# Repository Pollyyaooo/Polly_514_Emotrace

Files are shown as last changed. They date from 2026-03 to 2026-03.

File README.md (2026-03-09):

# EmoTrace
#### MSTI TECHIN 514 Final Project           
#### 01/06/2026-03/06/2026
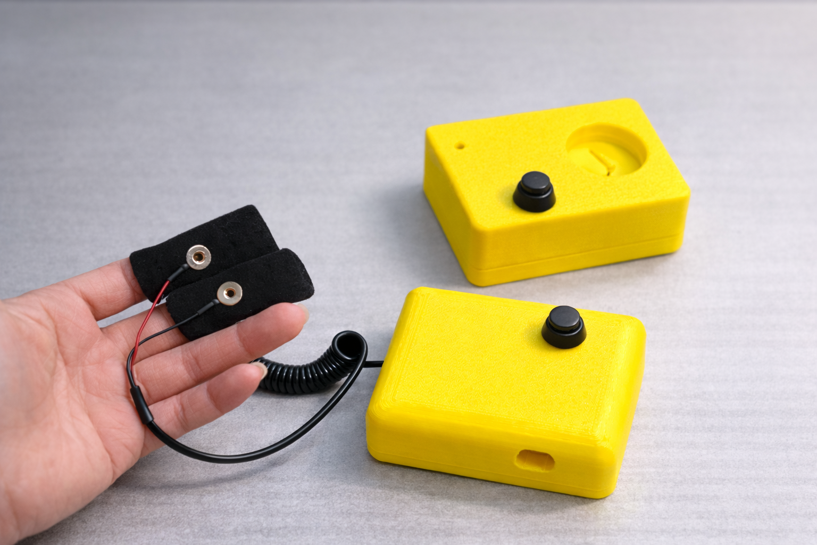
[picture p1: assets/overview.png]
overview


# OVERVIEW
## One Sentence Explanation
EmoTrace uses GSR to sense physiological arousal and express a person’s current emotional state in real time.

## Problem being Solved
Emotion is a continuously changing internal state, but it is difficult to observe directly. Most of the time, we only understand our emotions afterward, through memory or language, rather than seeing how they change in the moment.

If emotional states could be __externalized__, they might become something that both the individual and others can notice in real time.

## The Proposed Solution
EmoTrace measures physiological arousal through galvanic skin response (GSR) and expresses these changes using a stepper-motor-driven physical needle.

The system consists of two physically separated devices connected wirelessly via BLE: a sensing device, which captures and processes physiological signals, and a display device, which translates these signals into slow mechanical movement.

This separation allows the relationship between the person being sensed and the person observing the display to remain flexible. They can be the same person or different people. In this way, emotional states are externalized as a physical trace that can be noticed and reflected upon.

## Working Video

[Watch the demo video](https://drive.google.com/file/d/1t5GnzGR31K_5sYIAPt7pJoVDXnYhjY41/view?usp=sharing)

## System Architecture

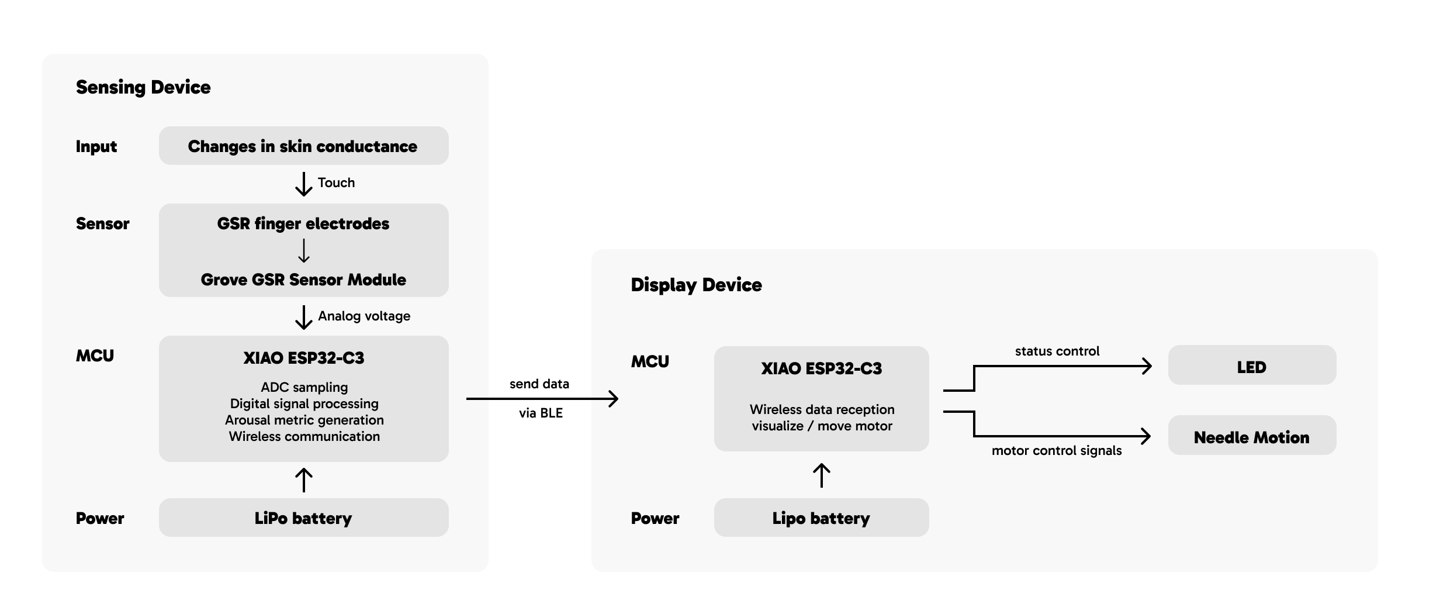
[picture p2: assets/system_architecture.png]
System Architecture


# SENSING DEVICE
## BOM
- 1 * [XIAO ESP32S3](https://www.digikey.com/en/products/detail/seeed-technology-co-ltd/113991054/16652880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)
- 1 * [1000mAh Lipo battery](https://www.digikey.com/en/products/detail/adafruit-industries-llc/258/5054544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)
- 1 * [Grove GSR Sensor](https://www.digikey.com/en/products/detail/seeed-technology-co-ltd/101020052/5488086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)
- 1 * [SPST Round Push Button Switch](https://www.walmart.com/ip/SPST-MOMENTARY-ON-PUSH-BUTTON-SWITCH-ROUND/166980349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)
- SMD resistors and capacitors
- Several JST connectors
- 3D printing enclosure

## Schematic Diagram
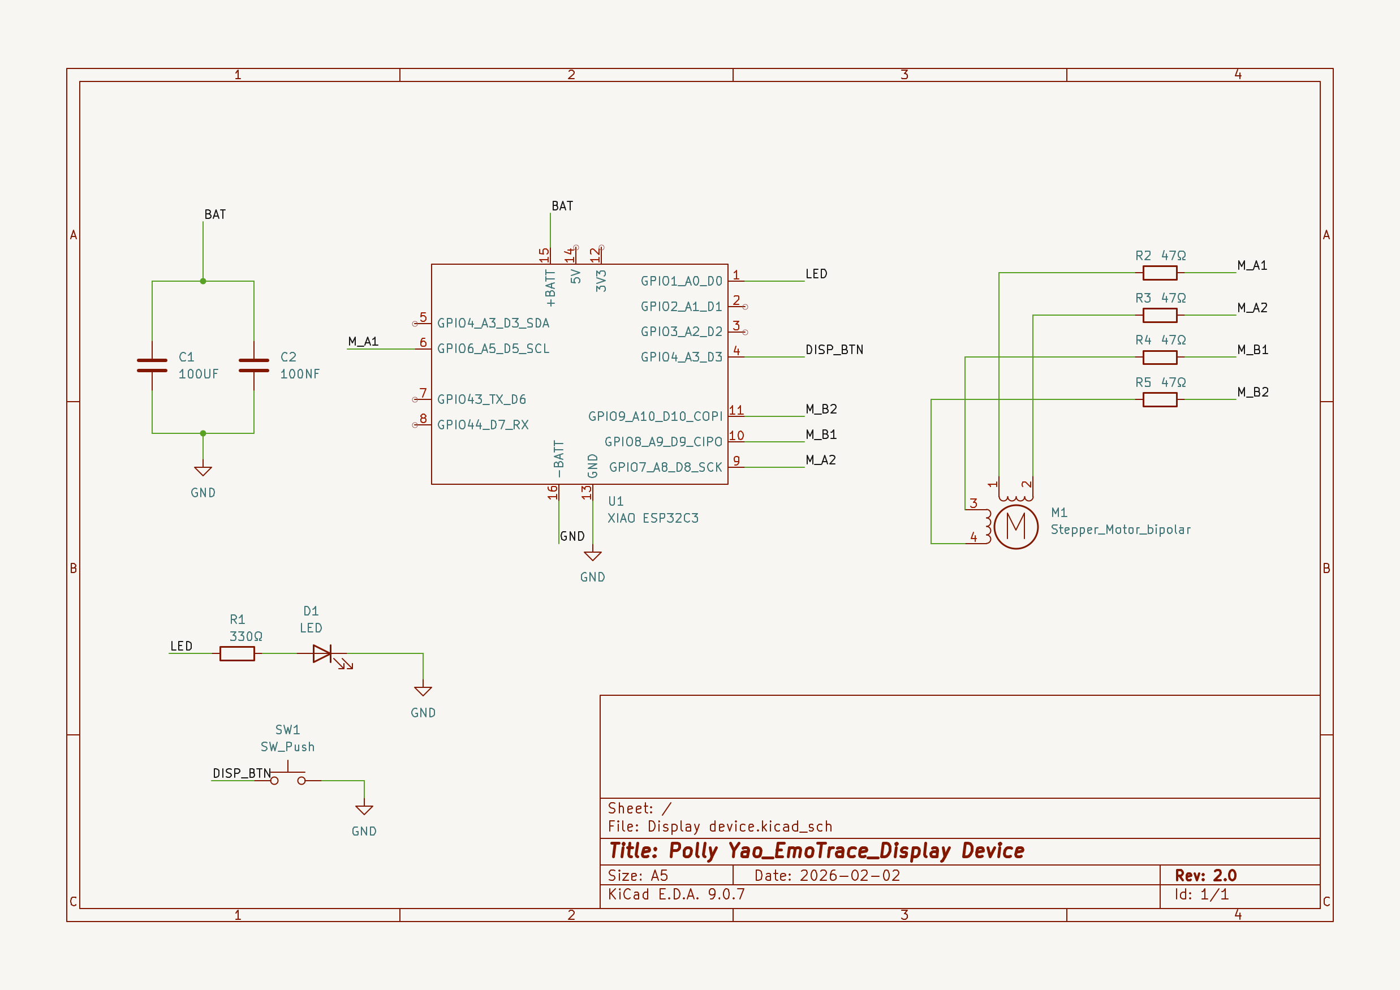
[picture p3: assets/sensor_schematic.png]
sensor_schematic


## Gallery
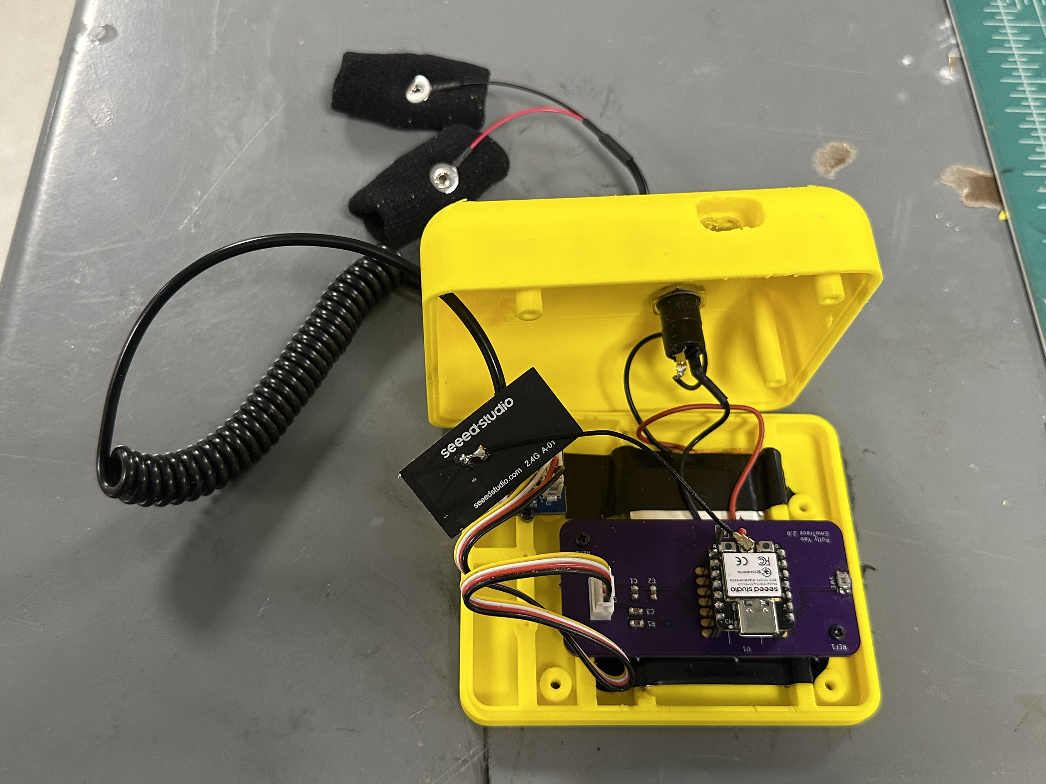
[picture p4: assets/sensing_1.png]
sensing_1

sensing_2

# DISPLAY DEVICE
## BOM
- 1 * [XIAO ESP32S3](https://www.digikey.com/en/products/detail/seeed-technology-co-ltd/113991054/16652880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)
- 1 * [820mAh Lipo battery](https://www.digikey.com/en/products/detail/adafruit-industries-llc/258/5054544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)
- 1 * [Stepper motor gauge](https://www.adafruit.com/product/2424)
- 1 * [SPST Round Push Button Switch](https://www.walmart.com/ip/SPST-MOMENTARY-ON-PUSH-BUTTON-SWITCH-ROUND/166980349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)
- SMD leds,resistors and capacitors
- 3D printing enclosure

## Schematic Diagram
display_schematic

## Gallery
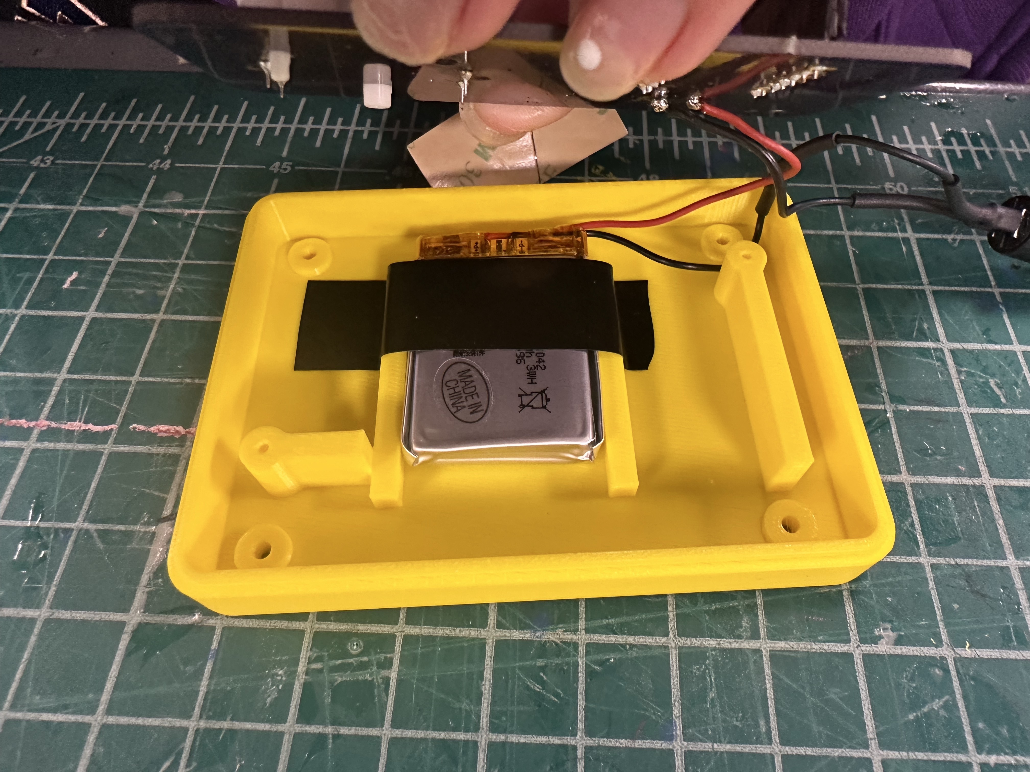
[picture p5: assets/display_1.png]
display_1

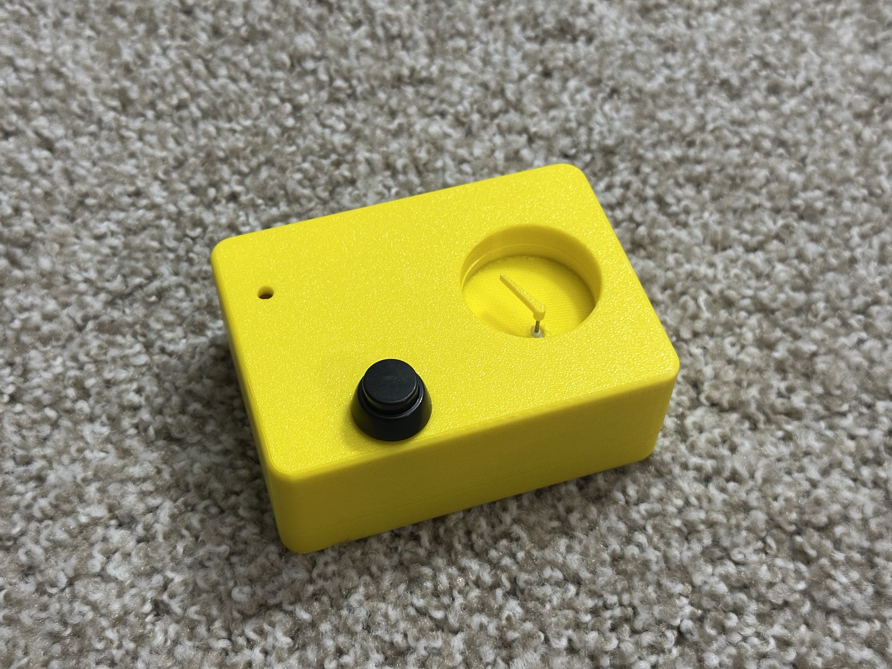
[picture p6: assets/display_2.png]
display_2


# BATTERY CONSIDERATIONS
Each device is powered by a LiPo battery with __a physical switch__ that can completely cut power to the ESP32, while __the onboard charging circuit__ allows the ESP32 to recharge the battery via USB; additionally, both devices implement __multiple operating states__ (off, monitoring/active for sensing and off, scanning/displaying for display) with light-sleep behavior to minimize continuous power consumption.

## Sensing Device
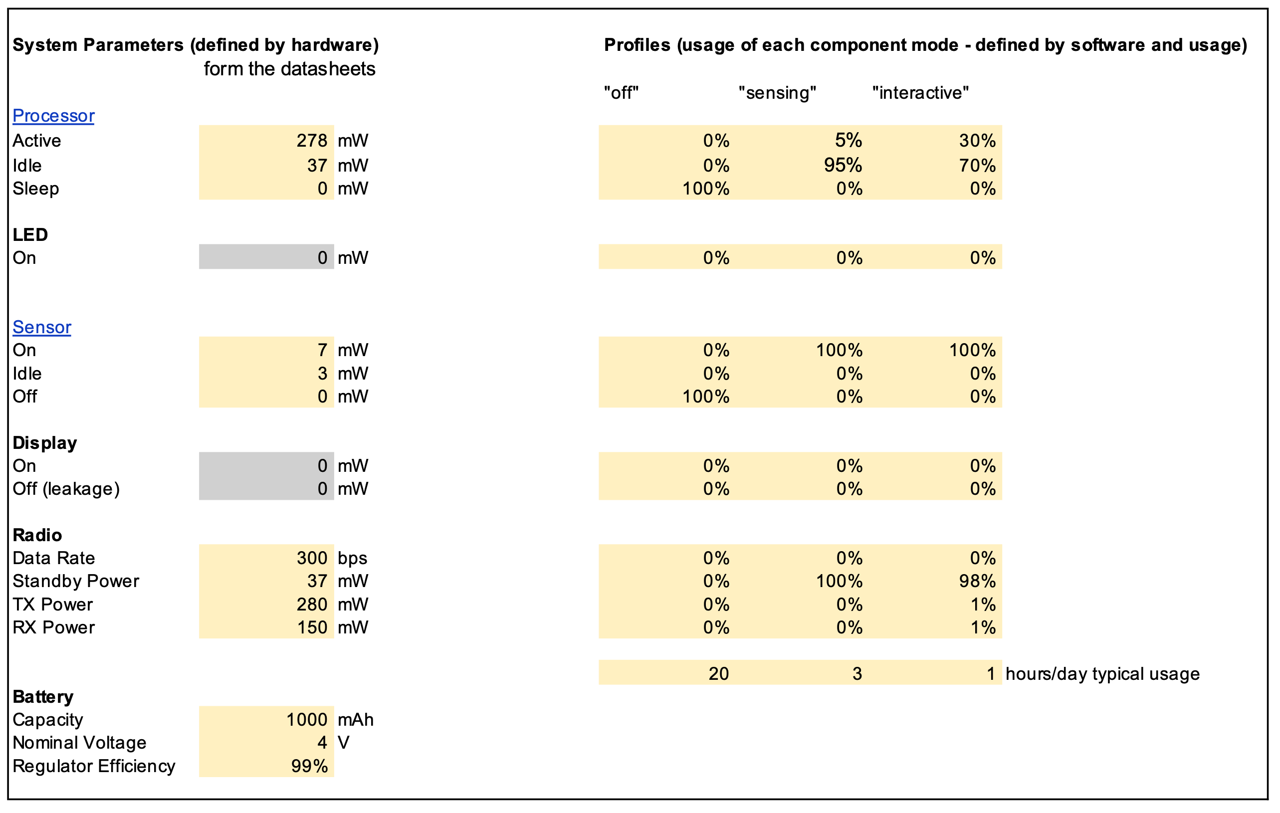
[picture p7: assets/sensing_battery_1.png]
batterysensing_1

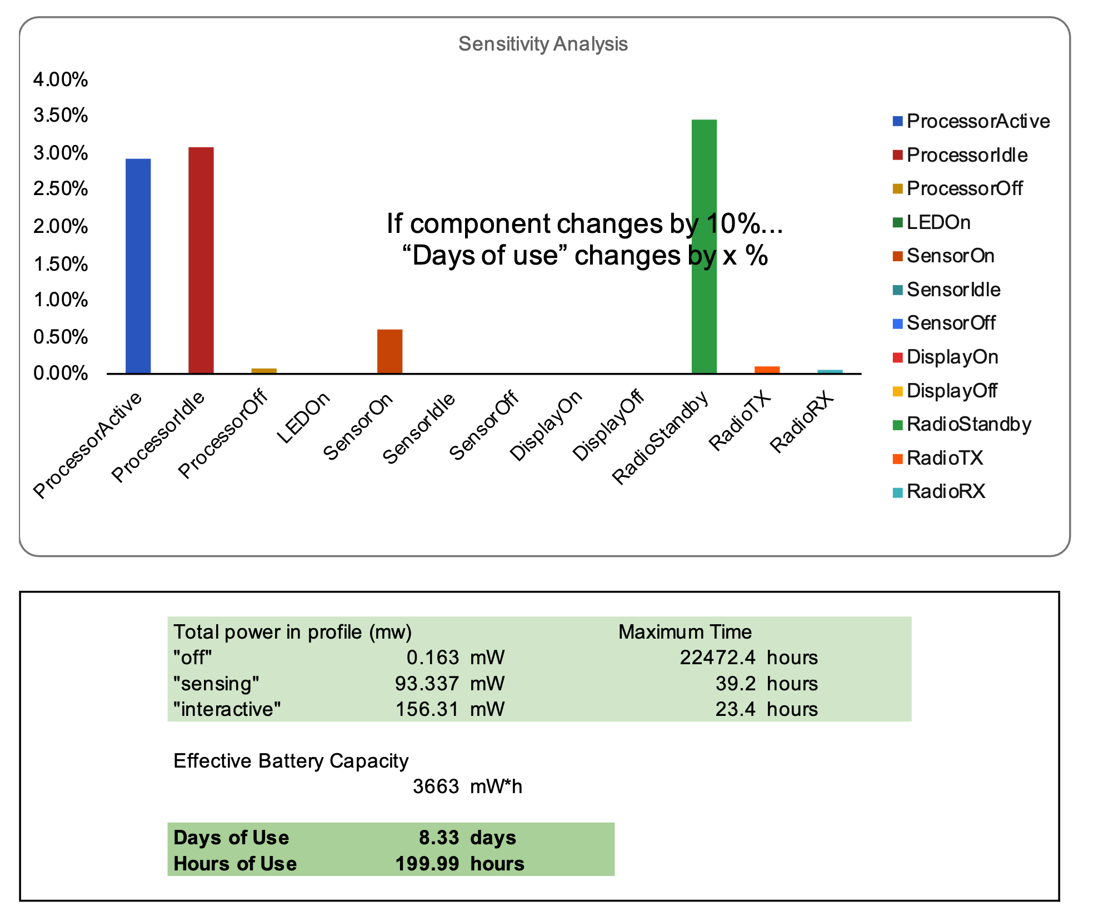
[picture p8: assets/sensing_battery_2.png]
batterysensing_2


Spreadsheet link:  
https://1drv.ms/x/c/3520740a59bca320/IQDMDjtJkVfMQYsOUzpoie-YAZGBVunHImL63yKkG8l4-dY?e=yHCJq8

## Display Device
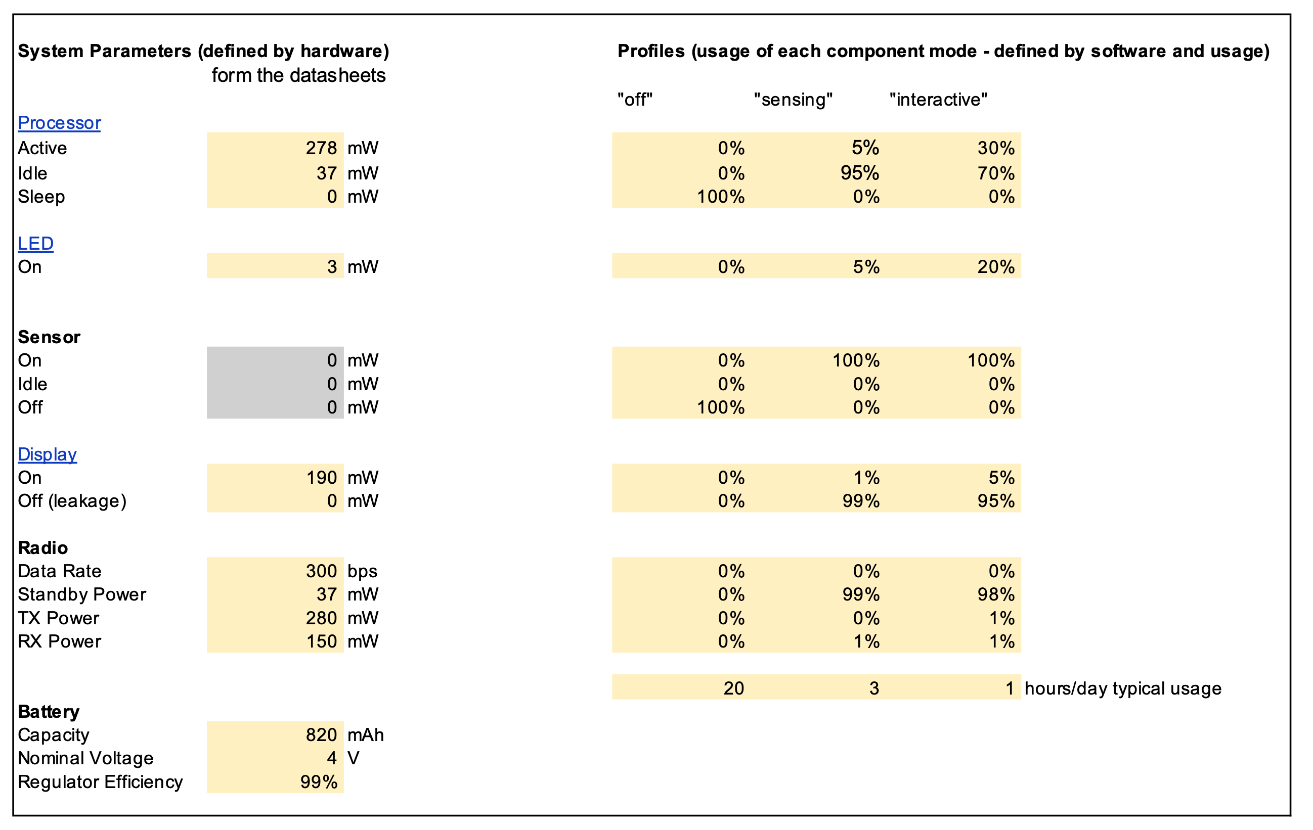
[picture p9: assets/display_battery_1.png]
batterydisplay_1

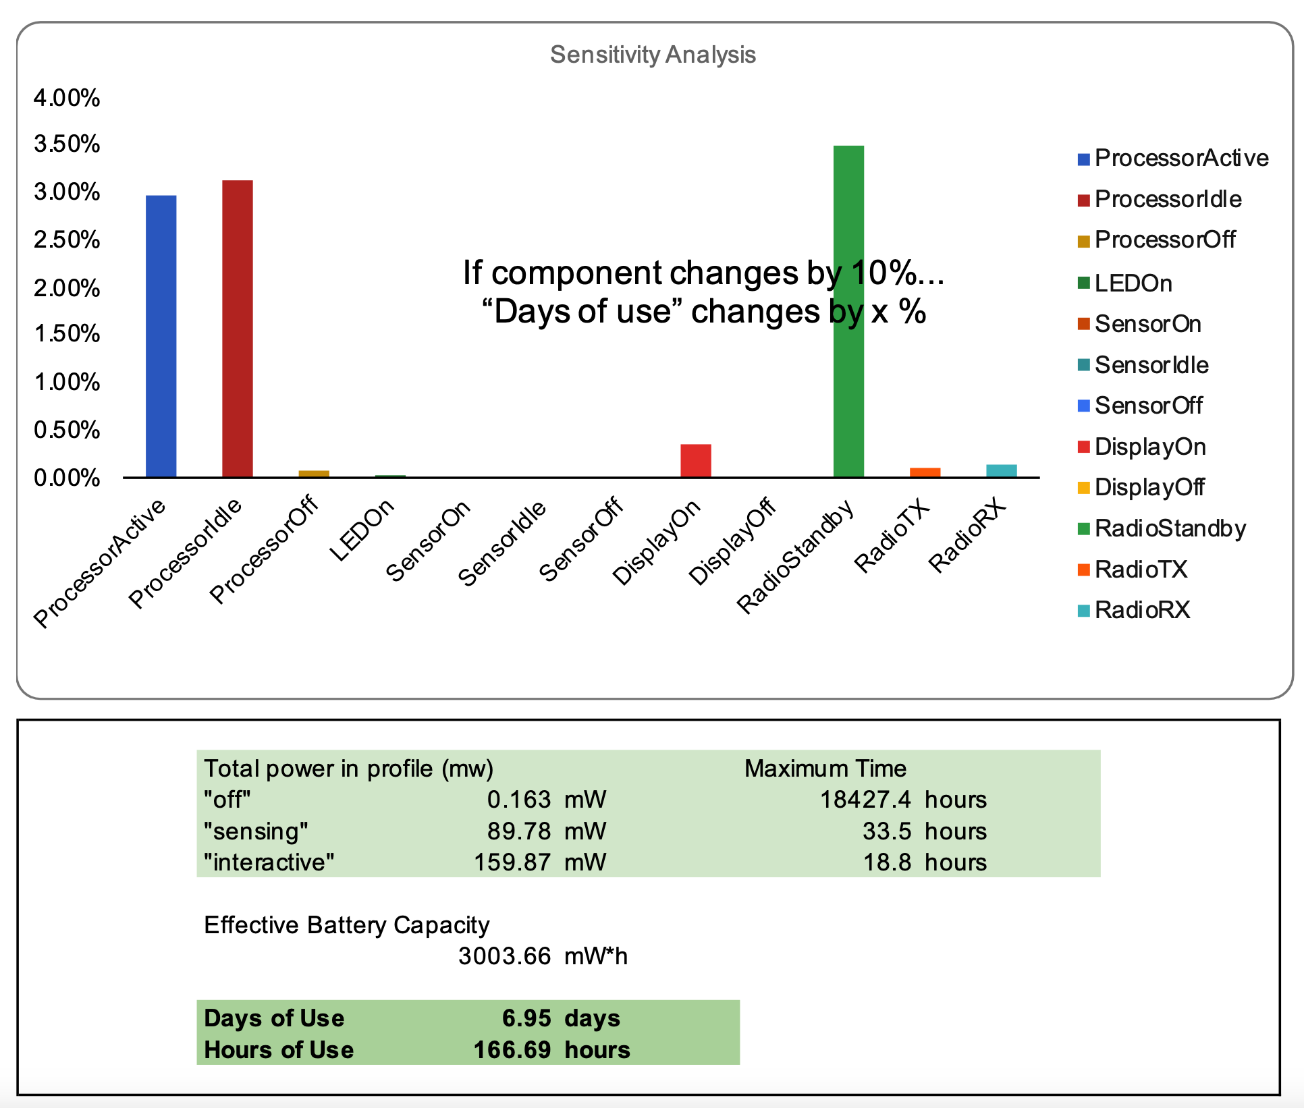
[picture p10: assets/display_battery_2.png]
batterydisplay_2


Spreadsheet link:  
https://1drv.ms/x/c/3520740a59bca320/IQBtffllcoQcSJlxG03brPWNAZ11j2MDRlCTxOjXR5vgqAk?e=tpQcXu

# BUDGET SUMMARY
| Component | Price |
|---|---|
| Grove GSR Module | $32.99 / $36.69 |
| CQRobot JST PH 2.0 mm Pitch Connector Kit | $6.99 / $7.71 |
| EVQ-P7A01P | $0.56 |
| ESP32C3 | $4.99 |
| **Total** | **$49.95** |

# FUTURE WORK
- Improved enclosure and interaction design
Develop a more refined enclosure with better integration of the charging port, button, and LED indicators, moving beyond the current PCB housing toward a more intentional human–device interaction.

- Multi-sensor emotional sensing
Incorporate additional physiological sensors to capture emotional states from multiple signals rather than relying solely on GSR.

- More robust signal processing
Improve data processing and filtering methods so that emotional changes are translated into clearer and more stable physical motion.

- Cost optimization
Explore alternative sourcing platforms to reduce the overall hardware cost of the system.

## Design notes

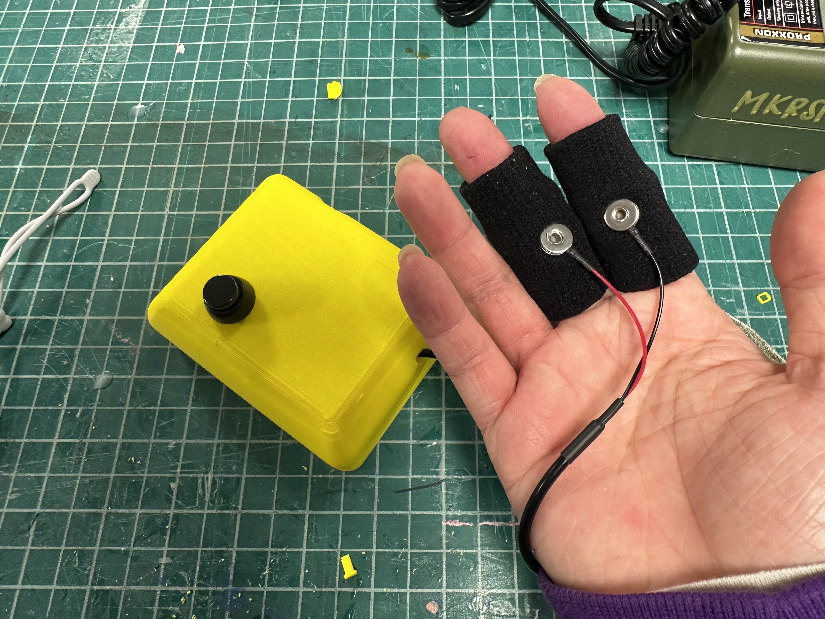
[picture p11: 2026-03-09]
assets/detailed_devices.png

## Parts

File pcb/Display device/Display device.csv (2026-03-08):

Source: | /Users/yaoyitong/Documents/Pollyyaooo-Polly_514_Final/schematics/Display device/Display device.kicad_sch
Date: | 2026-03-08T14:34:17-0700
Tool: | Eeschema 9.0.7
Generator: | /Applications/KiCad/KiCad.app/Contents/SharedSupport/plugins/bom_csv_grouped_by_value_with_fp.py
Component Count: | 11
Ref | Qnty | Value | Cmp name | Footprint | Description | Vendor | DNP
C1 | 1 | 100UF | C | Capacitor_SMD:C_0805_2012Metric_Pad1.18x1.45mm_HandSolder | Unpolarized capacitor
C2 | 1 | 100NF | C | Capacitor_SMD:C_0805_2012Metric_Pad1.18x1.45mm_HandSolder | Unpolarized capacitor
D1 | 1 | LED | LED | LED_SMD:LED_0805_2012Metric_Pad1.15x1.40mm_HandSolder | Light emitting diode
M1 | 1 | Stepper_Motor_bipolar | Stepper_Motor_bipolar | x27_Footprint:x27_stepper_two_holes | 4-wire bipolar stepper motor
R1 | 1 | 330Ω | R | Resistor_SMD:R_0805_2012Metric_Pad1.20x1.40mm_HandSolder | Resistor
R2, R3, R4, R5 | 4 | 47Ω | R_4 | Resistor_SMD:R_0805_2012Metric_Pad1.20x1.40mm_HandSolder | Resistor
SW1 | 1 | SW_Push | SW_Push | Button_Switch_SMD:SW_SPST_EVQP7A | Push button switch, generic, two pins
U1 | 1 | XIAO ESP32C3 | XIAO_ESP32 | GIX_ESP32:XIAO_ESP32

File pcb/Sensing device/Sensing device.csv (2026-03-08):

Source: | /Users/yaoyitong/Documents/Pollyyaooo-Polly_514_Final/schematics/Sensing device/Sensing device.kicad_sch
Date: | 2026-03-08T14:34:43-0700
Tool: | Eeschema 9.0.7
Generator: | /Applications/KiCad/KiCad.app/Contents/SharedSupport/plugins/bom_csv_grouped_by_value_with_fp.py
Component Count: | 7
Ref | Qnty | Value | Cmp name | Footprint | Description | Vendor | DNP
C1 | 1 | 10UF | C | Capacitor_SMD:C_0805_2012Metric_Pad1.18x1.45mm_HandSolder | Unpolarized capacitor
C2, C3 | 2 | 100NF | C | Capacitor_SMD:C_0805_2012Metric_Pad1.18x1.45mm_HandSolder | Unpolarized capacitor
J2 | 1 | Grove_GSR | Conn_01x04_Pin | Connector_JST:JST_PH_B4B-PH-K_1x04_P2.00mm_Vertical | Generic connector, single row, 01x04, script generated
R1 | 1 | 220Ω | R | Resistor_SMD:R_0805_2012Metric_Pad1.20x1.40mm_HandSolder | Resistor
SW1 | 1 | SW_Push | SW_Push | Button_Switch_SMD:SW_SPST_EVQP7A | Push button switch, generic, two pins
U1 | 1 | XIAO ESP32C3 | XIAO_ESP32 | GIX_ESP32:XIAO_ESP32

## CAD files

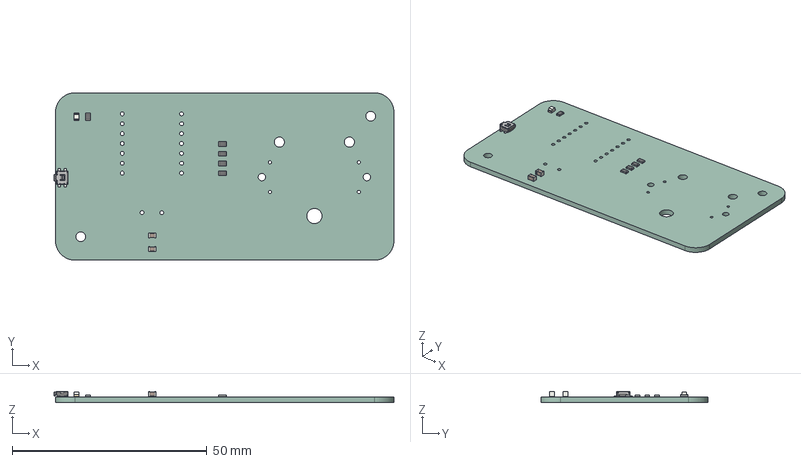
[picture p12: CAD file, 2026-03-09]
pcb/Display device/Display device.step
87.4 x 43.0 x 2.95 mm
LED_0805_2012Metric
R_0805_2012Metric x 5
SW_SPST_EVQP7A
C_0805_2012Metric x 2
Display device_PCB

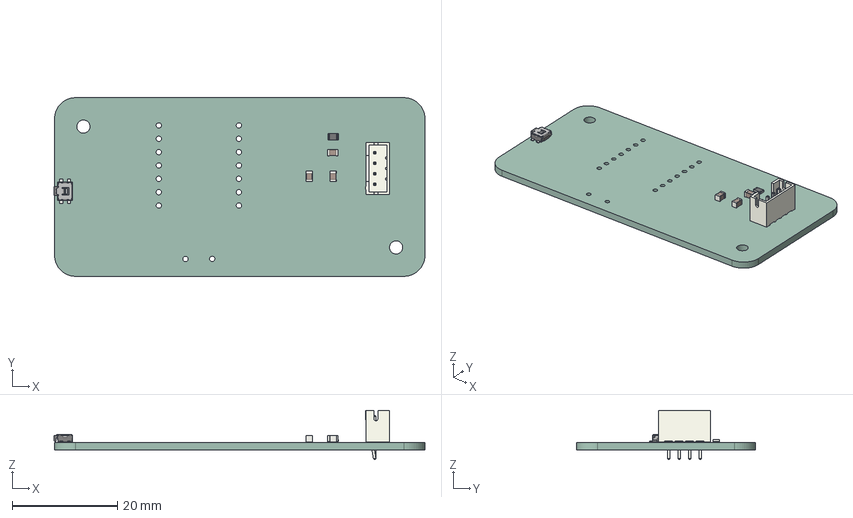
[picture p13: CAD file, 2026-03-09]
pcb/Sensing device/Sensing device.step
70.6 x 34.0 x 9.40 mm
SW_SPST_EVQP7A
C_0805_2012Metric x 3
JST_PH_B4B-PH-K_1x04_P2.00mm_Vertical
R_0805_2012Metric
Sensing device_PCB

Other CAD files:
models/Emotrace_Polly_Display.f3z
models/Emotrace_Polly_Sensing.f3z

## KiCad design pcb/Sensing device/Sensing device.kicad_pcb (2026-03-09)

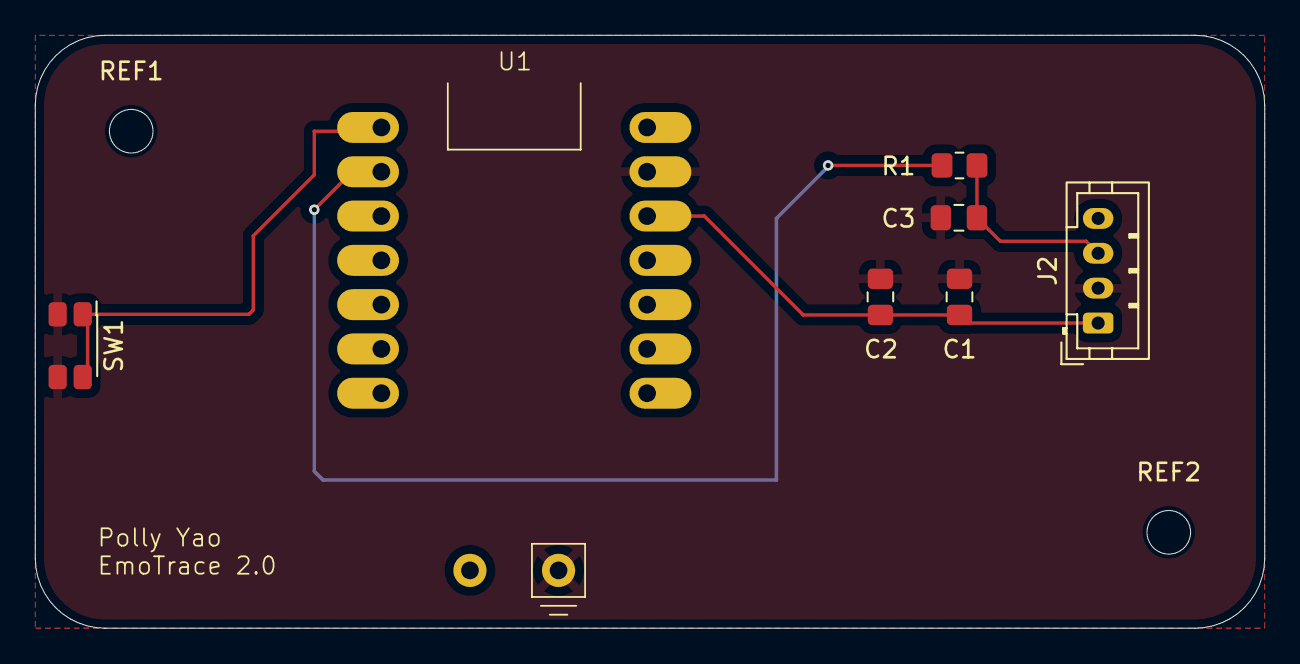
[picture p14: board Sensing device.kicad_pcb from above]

Board: 2 copper layers, 70.5 x 34.0 mm, 9 parts (0 on the bottom side), 5 nets.

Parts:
C1: 10uF; C_0805_2012Metric_Pad1.18x1.45mm_HandSolder
C2, C3: 0.1uF; C_0805_2012Metric_Pad1.18x1.45mm_HandSolder
J2: Grove_GSR; JST_PH_B4B-PH-K_1x04_P2.00mm_Vertical
R1: 220Ω; R_0805_2012Metric_Pad1.20x1.40mm_HandSolder
REF1, REF2: MountingHole_2.5mm
SW1: SW_Push; SW_SPST_EVQP7A
U1: XIAO ESP32C3; XIAO_ESP32

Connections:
+3V3: C1.1, C2.1, J2.1, U1.12 (3V3)
/CAL_BTN: SW1.1, U1.1 (GPIO1_A0_D0)
/GSR_SIG: R1.2, U1.2 (GPIO2_A1_D1)
GND: C1.2, C2.2, C3.1, J2.2, SW1.2, U1.13 (GND), U1.16 (-BATT)
unnamed: C3.2, J2.3, R1.1

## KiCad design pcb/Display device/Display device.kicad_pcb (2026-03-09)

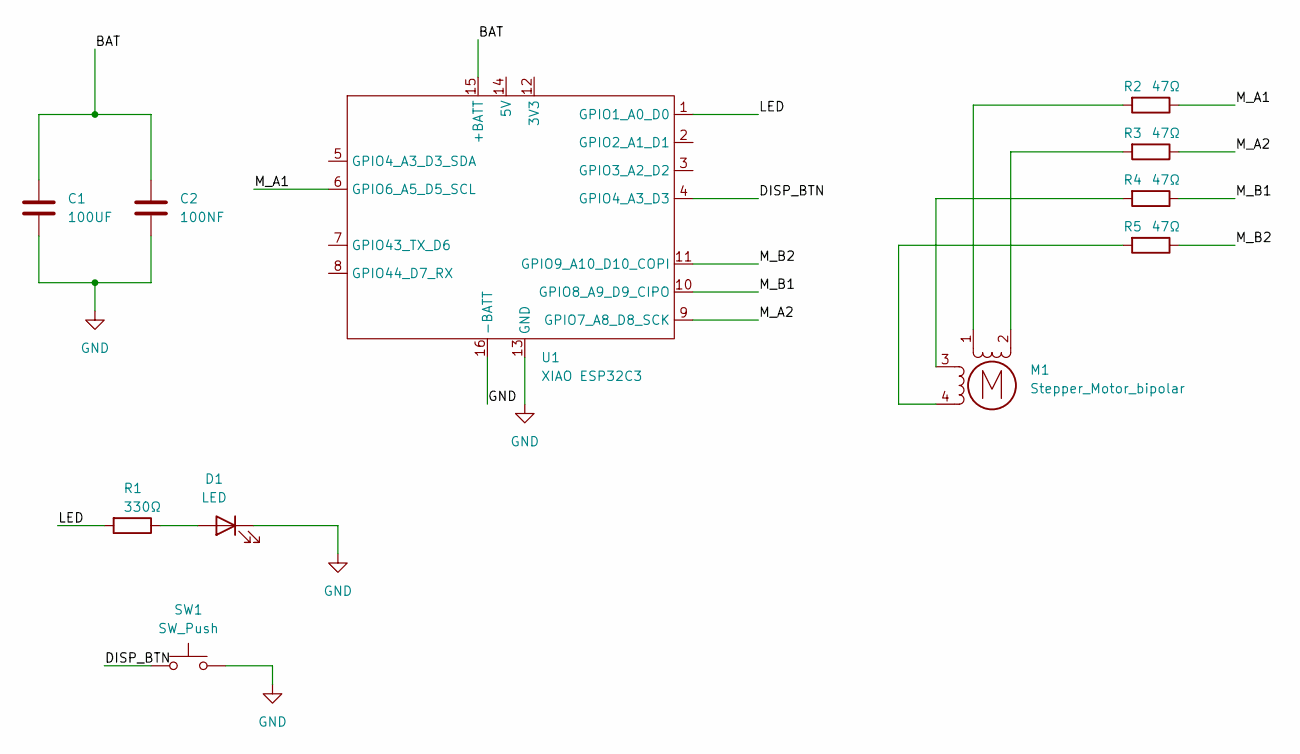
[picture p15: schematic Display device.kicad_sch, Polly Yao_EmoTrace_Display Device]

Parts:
C1: 100UF; C_0805_2012Metric_Pad1.18x1.45mm_HandSolder
C2: 100NF; C_0805_2012Metric_Pad1.18x1.45mm_HandSolder
D1: LED; LED_0805_2012Metric_Pad1.15x1.40mm_HandSolder
M1: Stepper_Motor_bipolar; x27_stepper_two_holes
R1: 330Ω; R_0805_2012Metric_Pad1.20x1.40mm_HandSolder
R2, R3, R4, R5: 47Ω; R_0805_2012Metric_Pad1.20x1.40mm_HandSolder
SW1: SW_Push; SW_SPST_EVQP7A
U1: XIAO ESP32C3; XIAO_ESP32

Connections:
/BAT: C1.1, C2.1, U1.15 (+BATT)
/DISP_BTN: SW1.1, U1.4 (GPIO4_A3_D3)
/LED: R1.2, U1.1 (GPIO1_A0_D0)
/M_A1: R2.1, U1.6 (GPIO6_A5_D5_SCL)
/M_A2: R3.1, U1.9 (GPIO7_A8_D8_SCK)
/M_B1: R4.1, U1.10 (GPIO8_A9_D9_CIPO)
/M_B2: R5.1, U1.11 (GPIO9_A10_D10_COPI)
GND: C1.2, C2.2, D1.1 (K), SW1.2, U1.13 (GND), U1.16 (-BATT)
unnamed: D1.2 (A), R1.1
unnamed: M1.2 (-), R3.2
unnamed: M1.1, R2.2
unnamed: M1.3, R4.2
unnamed: M1.4, R5.2

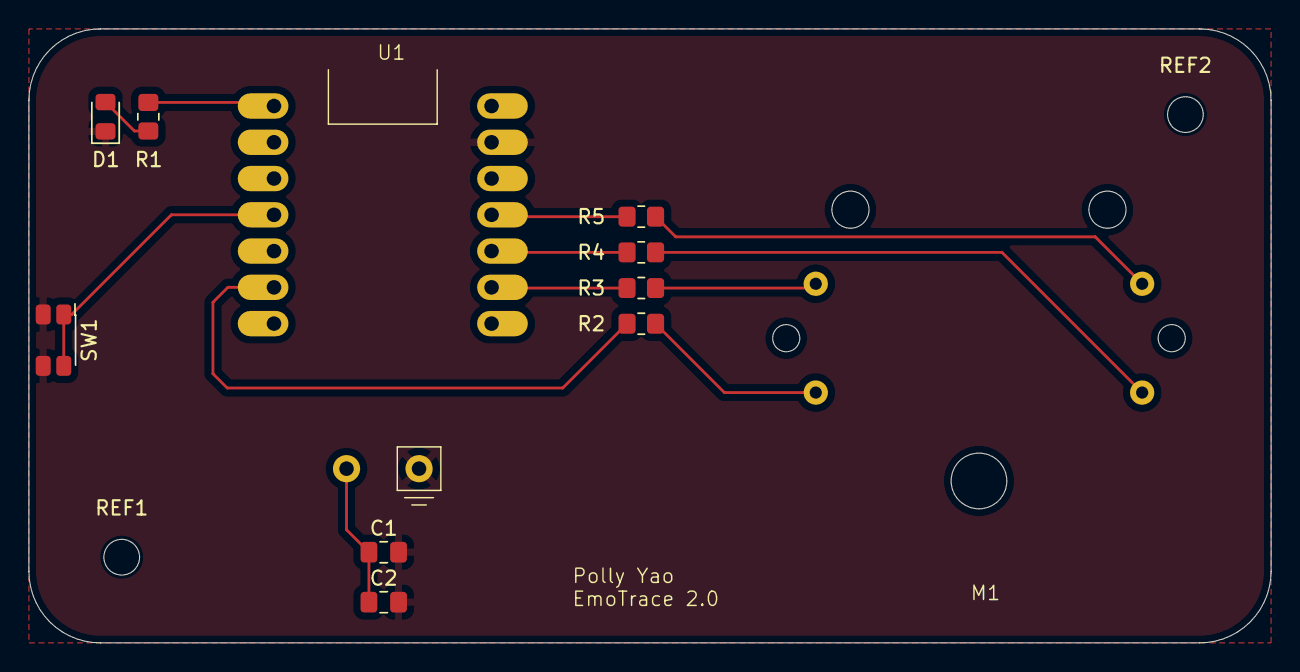
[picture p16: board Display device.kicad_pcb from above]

Board: 2 copper layers, 87.0 x 43.0 mm, 13 parts (0 on the bottom side), 13 nets.

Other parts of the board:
REF1, REF2: MountingHole_2.5mm

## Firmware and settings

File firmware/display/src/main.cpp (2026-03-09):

#include <Arduino.h>
#include <BLEDevice.h>
#include <BLEUtils.h>
#include <BLEScan.h>
#include <BLEAdvertisedDevice.h>

// ---------------- BLE ----------------
static BLEUUID serviceUUID("72e8ce72-67f1-4114-8412-1b0e1b35e0b1");
static BLEUUID charUUID("59ce0b83-f1c9-4229-9227-c6bd61ca7797");

static boolean doConnect = false;
static boolean connected = false;
static BLERemoteCharacteristic* pRemoteCharacteristic;
static BLEAdvertisedDevice* myDevice;

// ---------------- LED ----------------
#define LED_PIN D0

unsigned long ledTimer = 0;
bool ledState = false;

unsigned long lastNotifyTime = 0;

// ---------------- Device States ----------------
enum DeviceMode {
  MODE_SCANNING,
  MODE_DISPLAYING
};

DeviceMode currentMode = MODE_SCANNING;

// ---------------- Stepper Motor ----------------
#define A1 9
#define A2 10
#define B1 8
#define B2 5

int stepIndex = 0;
int currentStep = 0;
int targetStep = 0;

float smoothEmotion = 0;

const uint8_t seq[4][4] = {
  {1,0,1,0},
  {0,1,1,0},
  {0,1,0,1},
  {1,0,0,1}
};

// ---------------- LED Update ----------------
void updateLED() {

  // 最近0.5秒有收到数据 → 常亮
  if (millis() - lastNotifyTime < 500) {
    digitalWrite(LED_PIN, HIGH);
    return;
  }

  // 否则慢闪
  if (millis() - ledTimer > 100) {

    ledTimer = millis();
    ledState = !ledState;

    digitalWrite(LED_PIN, ledState);
  }
}

// ---------------- Motor ----------------
void stepMotor(int dir)
{
  stepIndex = (stepIndex + dir + 4) % 4;

  digitalWrite(A1, seq[stepIndex][0]);
  digitalWrite(A2, seq[stepIndex][1]);
  digitalWrite(B1, seq[stepIndex][2]);
  digitalWrite(B2, seq[stepIndex][3]);

  delay(6);
}

// ---------------- BLE Notify ----------------
static void notifyCallback(
  BLERemoteCharacteristic*,
  uint8_t* pData,
  size_t length,
  bool)
{
  if (length == 1) {

    lastNotifyTime = millis();

    uint8_t value = pData[0];

    smoothEmotion = smoothEmotion * 0.85 + value * 0.15;

    int angle = map((int)smoothEmotion, 0, 100, -60, 60);

    Serial.print("Emotion: ");
    Serial.print(value);
    Serial.print(" Smoothed: ");
    Serial.print(smoothEmotion);
    Serial.print(" → Angle: ");
    Serial.println(angle);

    targetStep = map(angle, -60, 60, 80, 420);
  }
}

// ---------------- BLE Client Callbacks ----------------
class MyClientCallback : public BLEClientCallbacks {

  void onConnect(BLEClient* pclient) {}

  void onDisconnect(BLEClient* pclient) {

    Serial.println("Disconnected → back to SCANNING");

    connected = false;
    currentMode = MODE_SCANNING;
  }
};

// ---------------- BLE Scan Callback ----------------
class MyAdvertisedDeviceCallbacks: public BLEAdvertisedDeviceCallbacks {

  void onResult(BLEAdvertisedDevice advertisedDevice) {

    if (advertisedDevice.haveServiceUUID() &&
        advertisedDevice.isAdvertisingService(serviceUUID)) {

      Serial.println("Sensing device found");

      BLEDevice::getScan()->stop();

      myDevice = new BLEAdvertisedDevice(advertisedDevice);

      doConnect = true;
    }
  }
};

// ---------------- Connect ----------------
bool connectToServer() {

  Serial.println("Connecting to sensing device...");

  BLEClient* pClient = BLEDevice::createClient();
  pClient->setClientCallbacks(new MyClientCallback());

  if (!pClient->connect(myDevice)) {

    Serial.println("Connection failed");

    return false;
  }

  Serial.println("Connected");

  BLERemoteService* pRemoteService =
      pClient->getService(serviceUUID);

  if (pRemoteService == nullptr) {

    Serial.println("Service not found");

    pClient->disconnect();

    return false;
  }

  pRemoteCharacteristic =
      pRemoteService->getCharacteristic(charUUID);

  if (pRemoteCharacteristic->canNotify()) {

    pRemoteCharacteristic->registerForNotify(notifyCallback);
  }

  connected = true;
  currentMode = MODE_DISPLAYING;

  Serial.println("Entering DISPLAYING mode");

  return true;
}

// ---------------- Setup ----------------
void setup() {

  Serial.begin(115200);
  delay(1000);
  Serial.println("Display device booting...");


  BLEDevice::init("");

  pinMode(A1, OUTPUT);
  pinMode(A2, OUTPUT);
  pinMode(B1, OUTPUT);
  pinMode(B2, OUTPUT);

  pinMode(LED_PIN, OUTPUT);

  currentStep = 250;
  targetStep = 250;

  BLEScan* pBLEScan = BLEDevice::getScan();

  pBLEScan->setAdvertisedDeviceCallbacks(
      new MyAdvertisedDeviceCallbacks());

  pBLEScan->setInterval(1349);
  pBLEScan->setWindow(449);
  pBLEScan->setActiveScan(true);
}

// ---------------- Loop ----------------
void loop() {

  updateLED();

  // ---------- SCANNING ----------
  if (currentMode == MODE_SCANNING) {

    BLEDevice::getScan()->start(3, false);

    if (doConnect) {

      if (connectToServer()) {

        Serial.println("Connected to BLE Server");
      }

      doConnect = false;
    }

    delay(100);
  }

  // ---------- DISPLAYING ----------
  if (currentMode == MODE_DISPLAYING) {

    int diff = targetStep - currentStep;

    if (abs(diff) > 10) {

      int dir = (diff > 0) ? 1 : -1;

      for(int i=0;i<3;i++) {
      stepMotor(dir);
      currentStep += dir;
     }

      currentStep = constrain(currentStep, 80, 420);
    }
  }
}

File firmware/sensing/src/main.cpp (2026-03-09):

#include <Arduino.h>
#include <BLEDevice.h>
#include <BLEServer.h>
#include <BLEUtils.h>
#include <BLE2902.h>

// ---------------- BLE ----------------
BLEServer* pServer = NULL;
BLECharacteristic* pCharacteristic = NULL;

bool deviceConnected = false;

#define SERVICE_UUID        "72e8ce72-67f1-4114-8412-1b0e1b35e0b1"
#define CHARACTERISTIC_UUID "59ce0b83-f1c9-4229-9227-c6bd61ca7797"

// ---------------- GSR ----------------
#define GSR_PIN A1

int rawGsr = 0;
int baseline = 0;
int emotionValue = 0;
float smoothEmotion = 0;

// ---------------- Timing ----------------
unsigned long previousMillis = 0;
unsigned long sampleInterval = 1000;

// ---------------- States ----------------
enum DeviceMode {
  MODE_MONITORING,
  MODE_ACTIVE
};

DeviceMode currentMode = MODE_MONITORING;

// 接触检测阈值
const int CONTACT_THRESHOLD = 2500;

// ---------------- BLE Callbacks ----------------
class MyServerCallbacks: public BLEServerCallbacks {

  void onConnect(BLEServer* pServer) {

    deviceConnected = true;

    Serial.println("Client connected");
  }

  void onDisconnect(BLEServer* pServer) {

    deviceConnected = false;

    Serial.println("Client disconnected");

    BLEDevice::startAdvertising(); // reconnect 必须
  }
};

// ---------------- Setup ----------------
void setup() {

  Serial.begin(115200);
  delay(2000);

  Serial.println("Sensing device booting...");

  pinMode(GSR_PIN, INPUT);

  baseline = analogRead(GSR_PIN);

  // -------- BLE 初始化（只一次） --------
  BLEDevice::init("EmoSense");

  pServer = BLEDevice::createServer();
  pServer->setCallbacks(new MyServerCallbacks());

  BLEService* pService = pServer->createService(SERVICE_UUID);

  pCharacteristic = pService->createCharacteristic(
      CHARACTERISTIC_UUID,
      BLECharacteristic::PROPERTY_READ |
      BLECharacteristic::PROPERTY_NOTIFY
  );

  pCharacteristic->addDescriptor(new BLE2902());

  uint8_t initValue = 0;
  pCharacteristic->setValue(&initValue, 1);

  pService->start();

  BLEAdvertising* pAdvertising = BLEDevice::getAdvertising();

  pAdvertising->addServiceUUID(SERVICE_UUID);
  pAdvertising->setScanResponse(true);

  BLEDevice::startAdvertising();

  Serial.println("BLE advertising started.");

  currentMode = MODE_MONITORING;

  Serial.println("Entering MONITORING mode");
}

// ---------------- Loop ----------------
void loop() {

  unsigned long currentMillis = millis();

  if (currentMillis - previousMillis >= sampleInterval) {

    previousMillis = currentMillis;

    rawGsr = analogRead(GSR_PIN);

    Serial.print("Raw: ");
    Serial.print(rawGsr);

    // ---------------- MONITORING ----------------
    if (currentMode == MODE_MONITORING) {

      Serial.println(" | Mode: MONITORING");

      if (rawGsr < CONTACT_THRESHOLD) {

        Serial.println("Contact detected → switching to ACTIVE");

        currentMode = MODE_ACTIVE;

        baseline = rawGsr;

        sampleInterval = 50;
      }

      return;
    }

    // ---------------- ACTIVE ----------------
    if (currentMode == MODE_ACTIVE) {

      // baseline slowly adapts
      baseline = baseline * 0.999 + rawGsr * 0.001;

      int delta = abs(rawGsr - baseline);
      if (delta < 5) delta = 0;

      int rawEmotion = map(delta, 0, 250, 0, 100);
      rawEmotion = constrain(rawEmotion, 0, 100);

      smoothEmotion = smoothEmotion * 0.8 + rawEmotion * 0.2;

      emotionValue = (int)smoothEmotion;

      Serial.print(" | Baseline: ");
      Serial.print(baseline);

      Serial.print(" | Emotion: ");
      Serial.print(emotionValue);

      Serial.println(" | Mode: ACTIVE");

      // 发送数据
      if (deviceConnected) {

        uint8_t data = emotionValue;

        pCharacteristic->setValue(&data, 1);
        pCharacteristic->notify();

        Serial.print("Notify: ");
        Serial.println(emotionValue);
      }

      // 如果检测不到接触 → 回到 monitoring
      if (rawGsr > CONTACT_THRESHOLD) {

        Serial.println("Contact lost → back to MONITORING");

        currentMode = MODE_MONITORING;

        sampleInterval = 1000;
      }
    }
  }
}

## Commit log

2026-03-08 schematics update
    [Display device.csv, Display device.kicad_sch, Sensing device.csv]
2026-03-08 battery management
    [Polly-display.xlsx, Polly-sensing.xlsx]
2026-03-09 readme update
    [Emotrace_Polly_Display.f3z, Emotrace_Polly_Sensing.f3z, Polly-display.xlsx]
